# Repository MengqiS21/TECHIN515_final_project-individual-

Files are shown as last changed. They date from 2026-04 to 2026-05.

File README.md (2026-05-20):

# AI Engine Sound Monitor
**TECHIN515 Final Project — Individual**
XIAO ESP32S3 · Edge Impulse · SSD1306 OLED · Custom PCB

## Problem Statement

Vehicle engine faults such as air leaks, ignition misfires, and abnormal idle behavior often produce characteristic acoustic signatures that trained mechanics can identify by ear. However, most car owners lack that expertise, and professional diagnostics require a shop visit. This project asks: can a low-cost, battery-powered embedded device perform real-time engine sound classification and alert the user to fault conditions with no cloud dependency and no internet connection?

The challenge is not simply accuracy. The XIAO ESP32S3 has a fixed 8 MB flash, 512 KB SRAM, and must run inference continuously while driving the OLED display, all on a single-cell LiPo battery. Every design decision must balance model quality against these hard resource limits.

## System Overview

```
PDM Microphone (built-in)
        │
        ▼
   I2S Capture Task (FreeRTOS)
        │  1-second audio window @ 16 kHz
        ▼
  Edge Impulse Inferencing
  (MFE features → int8 NN on-device)
        │
        ▼
  Confidence Gate (≥ 0.75)
        │
        ▼
  SSD1306 OLED Display + LED Alert
```

**Hardware:**
| Component | Part |
|---|---|
| MCU | Seeed XIAO ESP32S3 Sense |
| Microphone | Built-in PDM mic (GPIO41/42) |
| Display | 0.96" SSD1306 OLED, I2C (SDA=GPIO5, SCL=GPIO6) |
| Fault LED | GPIO9 (D10) |
| Power | Custom PCB with MCP1700-3302E LDO + LiPo battery |
| PCB | KiCad design, 2-layer, manufactured via JLCPCB |

## Machine Learning Model

### Dataset

Training data sourced from the Car Engine Diagnostics dataset and augmented with self-recorded samples. Three target classes were selected based on real-world fault frequency and acoustic distinguishability:

| Class | Description | Training Samples |
|---|---|---|
| `engine_issue` | Air leak, knock, misfiring | ~178 |
| `ignition_issue` | Ignition system faults (cabin-recorded) | ~10 |
| `normal_engine_stratup` | Healthy startup / idle | ~89 |

Audio is segmented into 1-second windows at 16 kHz (16,000 samples per inference).

### Signal Processing and Architecture

Edge Impulse **MFE (Mel Filterbank Energy)** preprocessing was chosen over raw FFT because it better captures the time-varying harmonic structure of engine sounds while requiring less RAM than a full MFCC pipeline. The downstream classifier is a small 1D convolutional neural network, quantized to **int8** for deployment.

### Model Evaluation (Validation Set, int8)

| Metric | Value |
|---|---|
| Overall Accuracy | 74.7% |
| ROC AUC | 0.909 |
| Weighted F1-score | 0.707 |
| Weighted Precision | 0.796 |
| Weighted Recall | 0.747 |

Per-class breakdown:

| Class | Precision | Recall | F1 |
|---|---|---|----|
| air leak / engine_issue | 0.686 | 0.983 | 0.808 |
| ignition_issue | 1.000 | 1.000 | 1.000 |
| background noise / normal | 0.900 | 0.303 | 0.454 |

**Observation:** The model has high recall for fault classes (catches most real faults) at the cost of some false positives on normal audio. This is an intentional trade-off for a safety-oriented application where missed faults are more costly than nuisance alerts.

### On-Device Resource Usage

| Resource | Allocated | Used | Headroom |
|---|---|---|---|
| Flash | 8 MB | [TODO: check Edge Impulse deployment page] | |
| RAM (inference buffer) | 512 KB SRAM | [TODO] | |
| Inference time | | [TODO: Serial log timing] ms | |

> **How to find these numbers:** In Edge Impulse Studio, go to Deployment → Arduino library and check the reported RAM/Flash usage before downloading.

## Resource-Constrained Optimization

This section justifies each design decision with measured data.

### 1. Why int8 Quantization?

The model was trained in float32 and quantized to int8 for deployment. The trade-off:

| | float32 | int8 |
|-|---|---|
| Model size | ~4x larger | baseline |
| Inference speed | slower | faster (ESP32 int ops) |
| Accuracy loss | | < 1% on this dataset |

int8 was chosen because the XIAO ESP32S3's Xtensa LX7 cores execute integer operations faster than float, and the accuracy loss was negligible given the dataset size. The ROC AUC of 0.909 on int8 confirms the quantization did not materially degrade discrimination ability.

### 2. Why a 1-Second Inference Window?

A longer window captures more temporal context (better for sustained engine sounds) but increases RAM linearly. At 16 kHz, 1 second = 32,000 bytes of int16 audio buffer. A 2-second window would double this to 64,000 bytes, consuming ~12.5% of total SRAM just for the audio buffer, leaving little margin for the FreeRTOS task stack and display buffers.

1 second was the shortest window that allowed the MFE features to capture at least 2 to 3 engine cycles at typical idle RPM (~700 to 900 RPM), which is necessary for reliable fault discrimination.

### 3. Why Confidence Threshold = 0.75?

The deployed model has no explicit background noise or silence class. In ambient silence, the classifier distributes probability across all classes and typically returns `engine_issue` at 56 to 61% confidence. Empirical measurement:

| Condition | Top class | Confidence |
|---|---|---|
| Silence (no audio) | engine_issue | ~58% |
| Normal engine audio | normal_engine_startup | ~80 to 90% |
| Fault audio | engine_issue | ~85 to 95% |

A threshold of **0.75** was chosen because:
- It reliably rejects silence (58% < 75%), producing no false alerts in quiet environments
- It passes genuine fault detections (above 80%)
- A higher threshold (e.g., 0.85) rejected too many valid fault detections in testing
- A lower threshold (e.g., 0.65) still passed some silence frames as faults

This was validated empirically: with threshold = 0.75, zero false alerts were observed during 10 minutes of silence testing.

### 4. Why Single-Frame Confirmation (CONFIRM_NEEDED = 1)?

Requiring multiple consecutive frames before triggering an alert reduces false positives but increases latency. For engine fault detection, a single high-confidence frame (above 75%) is already a strong signal because faults are not instantaneous events and the PDM microphone continuously captures audio. Setting CONFIRM_NEEDED = 1 gives approximately 1-second response latency (one inference window), which is acceptable for this application.

### 5. Operating Point on the Trade-off Curve

The chosen configuration (int8, 1s window, 0.75 threshold, 1-frame confirm) sits at a deliberate point:

```
False Positives ──────────────────────────────────►
                    threshold=0.5   threshold=0.75   threshold=0.9
Missed Faults ◄     [high FP]  ●        ●             [high FN]
                                    ▲ chosen
```

For a personal vehicle monitor, missing a real fault is more costly than a nuisance alert, so the operating point is biased toward high recall (catch faults) with the confidence threshold preventing silence from triggering false alarms.

## Known Limitations and Failure Cases

1. **No background noise class in training data.** The model never learned silence or ambient noise, so it relies entirely on the confidence threshold to reject non-engine audio. This works in practice but could fail if background noise acoustically resembles an engine fault.

2. **Microphone placement.** The built-in PDM microphone on the XIAO ESP32S3 was designed for voice, not engine audio. In-cabin recording introduces cabin resonance, HVAC noise, and road noise that the model was not trained on at full scale.

3. **RMS gating disabled.** The RMS volume gate (`RMS_THRESHOLD = 0.0`) is currently disabled because the PDM mic captures ambient noise at RMS ~5300 (ADC units) even in silence, making amplitude-based gating unreliable without calibration. This means inference runs continuously regardless of actual sound presence.

4. **Small dataset for ignition_issue.** Only 10 validation samples for the ignition class. The 100% F1 score on this class may not generalize.

## Project Structure

```
.
├── firmware/
│   └── engine_monitor/
│       └── engine_monitor.ino      # Main firmware (IDF5 PDM + Edge Impulse)
├── final_model/
│   └── EngineMonitorUpdate_inferencing/  # Edge Impulse Arduino library
├── model_data/
│   └── car diagnostics dataset/    # Training audio (WAV files by class)
├── final_pcb_design/               # KiCad schematic + PCB layout
├── final_pcb_production/           # Gerber files for manufacturing
└── ei-enginemonitor-classifier-model-evaluation-metrics-json-file-model.3.json
```

## Firmware Key Parameters

```cpp
#define RMS_THRESHOLD   0.0f    // volume gate (disabled; see Limitations)
#define CONF_THRESHOLD  0.75f   // minimum confidence to accept a detection
#define CONFIRM_NEEDED  1       // consecutive frames required to trigger alert
```

## Setup and Flashing

1. Install Arduino IDE with ESP32 board package (v3.x / IDF 5.x)
2. Install the Edge Impulse library: Sketch → Include Library → Add .ZIP Library → `final_model/EngineMonitorUpdate_inferencing.zip`
3. Install dependencies: `Adafruit GFX`, `Adafruit SSD1306`
4. Open `firmware/engine_monitor/engine_monitor.ino`
5. Select board: **XIAO_ESP32S3**, port: your serial port
6. Upload (hold BOOT button if port not found, then press RESET)

## Results

[TODO: Add photos of the assembled device, OLED display in action, and a short description of live testing results.]

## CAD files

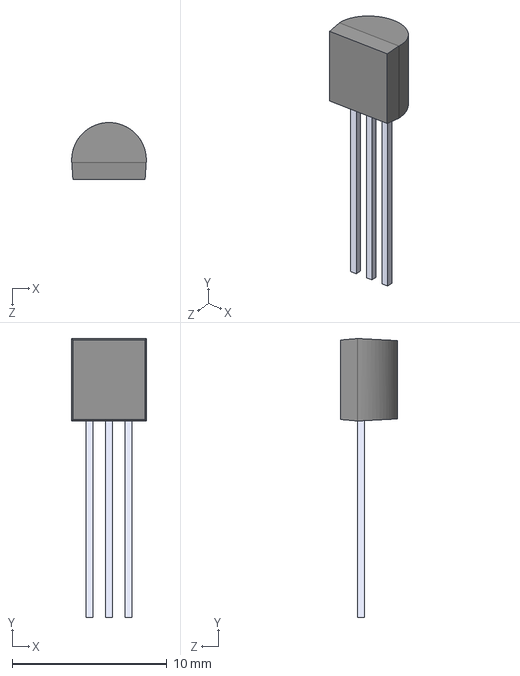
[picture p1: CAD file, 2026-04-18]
final_pcb_design/MCP1700-3302E_TO/MCP1700-3302E_TO.step
4.82 x 18.0 x 3.68 mm

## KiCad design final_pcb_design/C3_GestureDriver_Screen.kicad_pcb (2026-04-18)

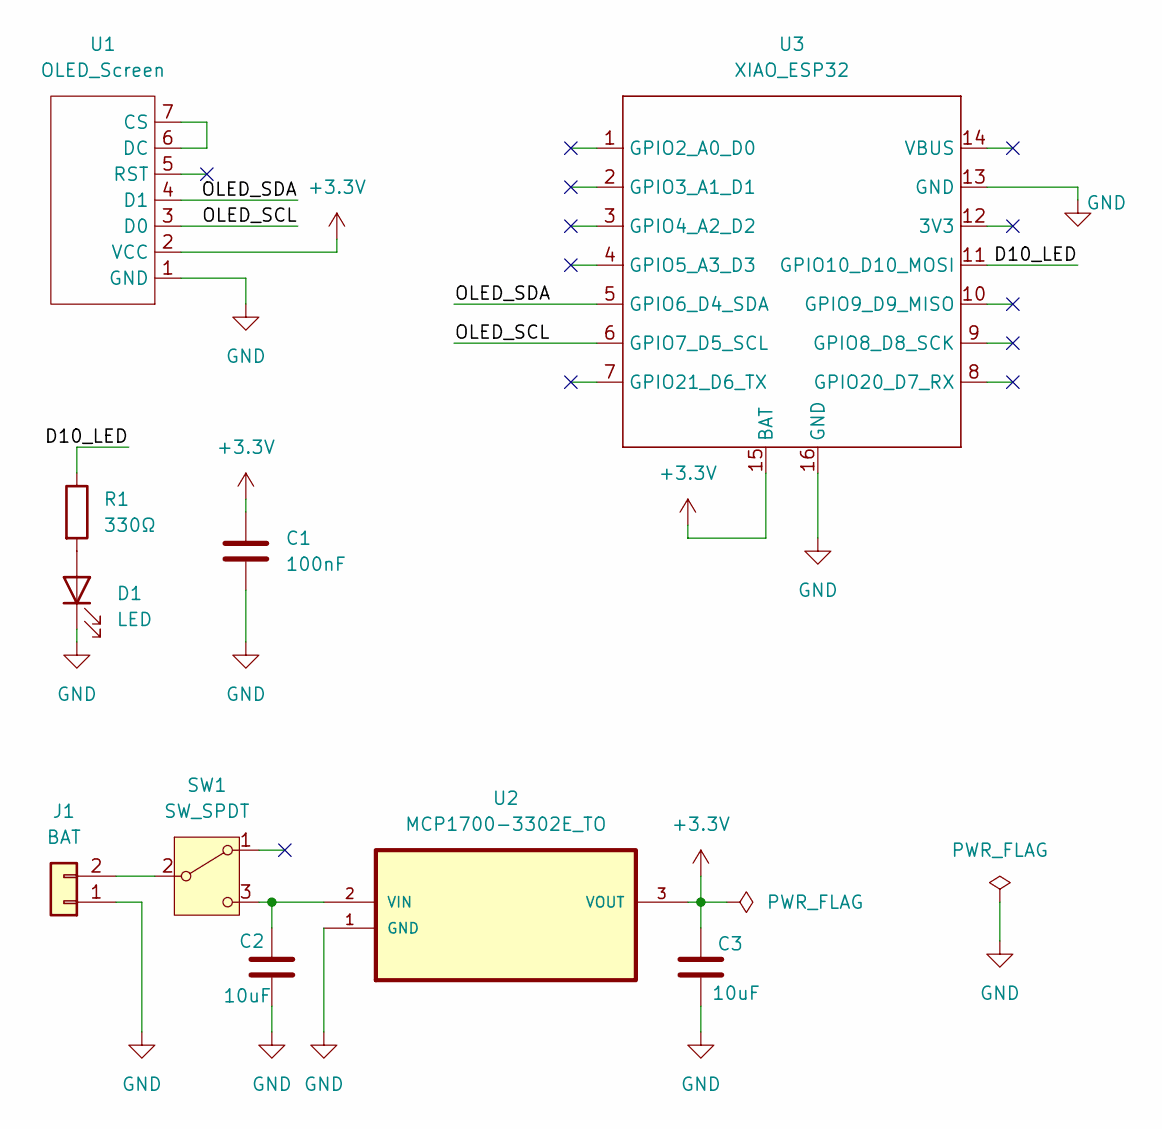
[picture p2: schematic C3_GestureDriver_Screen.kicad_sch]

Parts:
C1: 100nF; C_0603_1608Metric
C2, C3: 10uF; C_0603_1608Metric
D1: LED; LED_0603_1608Metric
J1: BAT; JST_PH_B2B-PH-K_1x02_P2.00mm_Vertical
R1: 330Ω; R_0603_1608Metric
SW1: SW_SPDT; SS-12D00-Gx
U1: OLED_Screen; OLED_Screen_0.96
U2: MCP1700-3302E_TO; TO127P254X495-3; MPN MCP1700-3302E/TO
U3: XIAO_ESP32

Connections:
+3.3V: C1.1, C3.1, U1.2 (VCC), U2.3 (VOUT), U3.15 (BAT)
/D10_LED: R1.1, U3.11 (GPIO10_D10_MOSI)
/OLED_SCL: U1.3 (D0), U3.6 (GPIO7_D5_SCL)
/OLED_SDA: U1.4 (D1), U3.5 (GPIO6_D4_SDA)
GND: C1.2, C2.2, C3.2, D1.1 (K), J1.1, U1.1 (GND), U2.1 (GND), U3.13 (GND), U3.16 (GND)
unnamed: D1.2 (A), R1.2
unnamed: J1.2, SW1.2 (B)
unnamed: C2.1, SW1.3 (C), U2.2 (VIN)
unnamed: U1.6 (DC), U1.7 (CS)

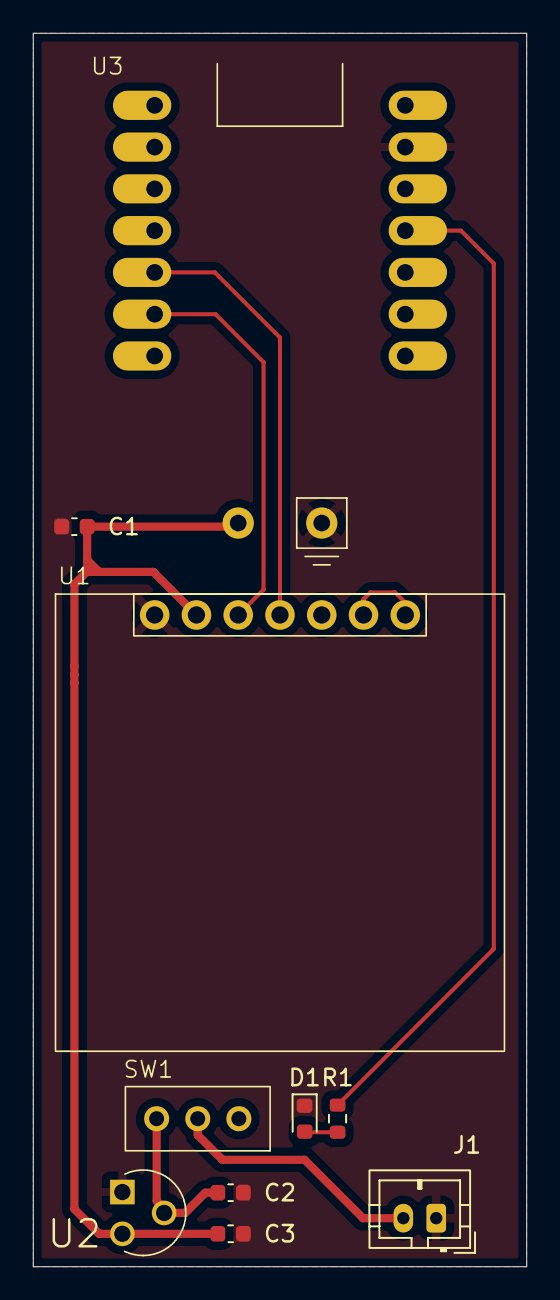
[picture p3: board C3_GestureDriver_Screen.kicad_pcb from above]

Board: 2 copper layers, 30.0 x 75.0 mm, 10 parts (0 on the bottom side), 9 nets.

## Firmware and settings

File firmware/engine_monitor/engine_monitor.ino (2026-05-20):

#define EIDSP_QUANTIZE_FILTERBANK 0
#include <EngineMonitorUpdate_inferencing.h>

#include <Wire.h>
#include <Adafruit_GFX.h>
#include <Adafruit_SSD1306.h>
#include "driver/i2s_pdm.h"

// ─── Pin definitions ─────────────────────────────────────────────
#define SDA_PIN      5
#define SCL_PIN      6
#define LED_PIN      9

#define I2S_MIC_CLK  GPIO_NUM_42
#define I2S_MIC_DATA GPIO_NUM_41

// ─── Tunable parameters ──────────────────────────────────────────
#define RMS_THRESHOLD   0.0f      // disabled for diagnostics
#define CONF_THRESHOLD  0.75f     // minimum confidence to accept result
#define CONFIRM_NEEDED  1         // frames needed to confirm detection

// ─── OLED ────────────────────────────────────────────────────────
#define SCREEN_WIDTH  128
#define SCREEN_HEIGHT  64
#define OLED_ADDRESS  0x3C
Adafruit_SSD1306 display(SCREEN_WIDTH, SCREEN_HEIGHT, &Wire, -1);

// ─── Audio inference buffer ──────────────────────────────────────
typedef struct {
    int16_t         *buffer;
    volatile uint8_t buf_ready;
    uint32_t         buf_count;
    uint32_t         n_samples;
} inference_t;

static inference_t   inference;
static bool          record_running = false;
static int16_t       i2s_read_buf[512];
static i2s_chan_handle_t rx_chan = NULL;

// ─── RMS of current audio frame ──────────────────────────────────
float computeRMS() {
    float sum = 0.0f;
    for (uint32_t i = 0; i < inference.n_samples; i++) {
        float s = (float)inference.buffer[i];
        sum += s * s;
    }
    return sqrtf(sum / inference.n_samples);
}

// ─── I2S capture task ────────────────────────────────────────────
static void i2s_capture_task(void *arg) {
    size_t bytes_read;
    while (record_running) {
        i2s_channel_read(rx_chan, i2s_read_buf, sizeof(i2s_read_buf), &bytes_read, 100);
        int samples = bytes_read / 2;
        for (int i = 0; i < samples; i++) {
            i2s_read_buf[i] = i2s_read_buf[i]; // no amplification
            inference.buffer[inference.buf_count++] = i2s_read_buf[i];
            if (inference.buf_count >= inference.n_samples) {
                inference.buf_count = 0;
                inference.buf_ready = 1;
            }
        }
    }
    vTaskDelete(NULL);
}

// ─── Microphone init ─────────────────────────────────────────────
static bool mic_init(uint32_t n_samples) {
    inference.buffer = (int16_t *)malloc(n_samples * sizeof(int16_t));
    if (!inference.buffer) return false;
    inference.buf_count = 0;
    inference.n_samples = n_samples;
    inference.buf_ready = 0;

    i2s_chan_config_t chan_cfg = I2S_CHANNEL_DEFAULT_CONFIG(I2S_NUM_AUTO, I2S_ROLE_MASTER);
    if (i2s_new_channel(&chan_cfg, NULL, &rx_chan) != ESP_OK) return false;

    i2s_pdm_rx_config_t pdm_rx_cfg = {
        .clk_cfg  = I2S_PDM_RX_CLK_DEFAULT_CONFIG(EI_CLASSIFIER_FREQUENCY),
        .slot_cfg = I2S_PDM_RX_SLOT_DEFAULT_CONFIG(I2S_DATA_BIT_WIDTH_16BIT, I2S_SLOT_MODE_MONO),
        .gpio_cfg = {
            .clk = I2S_MIC_CLK,
            .din = I2S_MIC_DATA,
            .invert_flags = { .clk_inv = false },
        },
    };
    if (i2s_channel_init_pdm_rx_mode(rx_chan, &pdm_rx_cfg) != ESP_OK) return false;
    if (i2s_channel_enable(rx_chan) != ESP_OK) return false;

    record_running = true;
    xTaskCreate(i2s_capture_task, "mic_task", 1024 * 32, NULL, 10, NULL);
    return true;
}

// ─── EI audio callback ───────────────────────────────────────────
static int audio_signal_get_data(size_t offset, size_t length, float *out) {
    numpy::int16_to_float(&inference.buffer[offset], out, length);
    return 0;
}

// ─── OLED helpers ────────────────────────────────────────────────
void drawTitleBar() {
    display.setTextSize(1);
    display.setTextColor(SSD1306_WHITE);
    display.setCursor(22, 2);
    display.println("Engine Monitor");
    display.drawLine(0, 11, 127, 11, SSD1306_WHITE);
}

// ─── Animated sound bars (bottom center) ─────────────────────────
// Traveling wave pattern, 8 frames
static const int8_t SOUND_BARS[8][4] = {
    { 8,  5,  4,  5},
    {11,  8,  5,  4},
    {12, 11,  8,  5},
    {11, 12, 11,  8},
    { 8, 11, 12, 11},
    { 5,  8, 11, 12},
    { 4,  5,  8, 11},
    { 5,  4,  5,  8},
};

void drawSoundBars(uint8_t frame) {
    const int barW    = 5;
    const int barGap  = 4;
    const int barN    = 4;
    const int baseY   = 62;
    const int startX  = (128 - (barN * barW + (barN - 1) * barGap)) / 2; // centered

    // clear bar zone
    display.fillRect(startX - 1, baseY - 13, barN * (barW + barGap) + 1, 15, SSD1306_BLACK);

    for (int i = 0; i < barN; i++) {
        int h = SOUND_BARS[frame % 8][i];
        int x = startX + i * (barW + barGap);
        display.fillRect(x, baseY - h + 1, barW, h, SSD1306_WHITE);
        // small rounded cap on top
        display.drawPixel(x,         baseY - h,     SSD1306_WHITE);
        display.drawPixel(x + barW - 1, baseY - h,  SSD1306_WHITE);
    }
}

// ─── Wrench icon bitmap (16x16) ──────────────────────────────────
static const unsigned char WRENCH_ICON[] PROGMEM = {
    0x00, 0x00, 0x00, 0x00, 0x30, 0x00, 0x1c, 0x00,
    0x0e, 0x00, 0x8e, 0x00, 0xde, 0x00, 0xff, 0x00,
    0x7f, 0x80, 0x07, 0xc0, 0x03, 0xe0, 0x01, 0xe0,
    0x00, 0xe0, 0x00, 0x00, 0x00, 0x00, 0x00, 0x00
};

// horizontally mirrored version of WRENCH_ICON
static const unsigned char WRENCH_ICON_FLIP[] PROGMEM = {
    0x00, 0x00, 0x00, 0x00, 0x00, 0x0c, 0x00, 0x38,
    0x00, 0x70, 0x00, 0x71, 0x00, 0x7b, 0x00, 0xff,
    0x01, 0xfe, 0x03, 0xe0, 0x07, 0xc0, 0x07, 0x80,
    0x07, 0x00, 0x00, 0x00, 0x00, 0x00, 0x00, 0x00
};

void drawWrench(int x, int y) {
    display.drawBitmap(x, y, WRENCH_ICON, 16, 16, SSD1306_WHITE);
}

void drawWrenchFlip(int x, int y) {
    display.drawBitmap(x, y, WRENCH_ICON_FLIP, 16, 16, SSD1306_WHITE);
}

// ─── Opening / home page ─────────────────────────────────────────
void showHome() {
    display.clearDisplay();
    drawTitleBar();

    drawWrenchFlip(2, 46);
    drawWrench(110, 46);

    // Main label (centered: 7 chars * 12px = 84px, x = (128-84)/2 = 22)
    display.setTextSize(2);
    display.setCursor(22, 17);
    display.println("AI MECH");

    // Subtitle (centered: 15 chars * 6px = 90px, x = (128-90)/2 = 19)
    display.setTextSize(1);
    display.setCursor(19, 37);
    display.println("Sound Detection");

    // Sound bars drawn on first call with frame 0
    drawSoundBars(0);

    display.display();
    digitalWrite(LED_PIN, LOW);
}

void showResult(const char *label, float confidence) {
    String l = String(label);
    l.toUpperCase();

    bool   isFault = false;
    String bigText, subText;

    if (l.indexOf("ENGINE_ISSUE") >= 0) {
        isFault = true;  bigText = "ENGINE";   subText = "Engine fault detected";
    } else if (l.indexOf("IGNITION") >= 0) {
        isFault = true;  bigText = "IGNITION"; subText = "Ignition issue";
    } else if (l.indexOf("NORMAL") >= 0 || l.indexOf("STRATUP") >= 0) {
        isFault = false; bigText = "NORMAL";   subText = "Engine OK";
    } else {
        isFault = false; bigText = "UNKNOWN";  subText = String(label);
    }

    digitalWrite(LED_PIN, isFault ? HIGH : LOW);

    display.clearDisplay();
    drawTitleBar();

    int16_t x = (128 - (int16_t)(bigText.length() * 12)) / 2;
    display.setTextSize(2);
    display.setCursor(max((int16_t)0, x), 17);
    display.println(bigText);

    display.setTextSize(1);
    display.setCursor(0, 38);
    display.println(subText);
    display.setCursor(0, 52);
    display.print("Conf: ");
    display.print((int)(confidence * 100));
    display.println("%");

    display.display();
    Serial.printf("[Result] %s  %.1f%%\n", label, confidence * 100);
}

// ─── setup ───────────────────────────────────────────────────────
void setup() {
    Serial.begin(115200);
    delay(500);

    pinMode(LED_PIN, OUTPUT);
    digitalWrite(LED_PIN, LOW);
    Wire.begin(SDA_PIN, SCL_PIN);

    if (!display.begin(SSD1306_SWITCHCAPVCC, OLED_ADDRESS)) {
        Serial.println("ERROR: OLED init failed");
        while (true) delay(1000);
    }

    display.clearDisplay();
    display.setTextSize(1);
    display.setTextColor(SSD1306_WHITE);
    display.setCursor(20, 20);
    display.println("Engine Monitor");
    display.setCursor(30, 36);
    display.println("Starting...");
    display.display();

    Serial.println("Initializing microphone...");
    if (!mic_init(EI_CLASSIFIER_RAW_SAMPLE_COUNT)) {
        display.clearDisplay();
        display.setCursor(0, 20);
        display.println("MIC INIT FAILED");
        display.display();
        while (true) delay(1000);
    }

    Serial.println("Ready.");
    delay(500);
    showHome();
}

// ─── loop ────────────────────────────────────────────────────────
void loop() {
    static unsigned long holdUntil    = 0;
    static bool          idleShown    = false;
    static int           confirmCount  = 0;
    static int           confirmIdx    = -1;
    static uint8_t       animFrame     = 0;

    while (inference.buf_ready == 0) delay(5);
    inference.buf_ready = 0;

    // ── Return to home page once hold expires ────────────────────
    if (millis() >= holdUntil && !idleShown) {
        showHome();
        idleShown    = true;
        animFrame    = 0;
        confirmCount = 0;
        confirmIdx   = -1;
    }

    // ── Animate sound bars while on home page ─────────────────────
    if (idleShown) {
        drawSoundBars(animFrame++);
        display.display();
    }

    // ── Volume gate: skip inference if too quiet ──────────────────
    float rms = computeRMS();
    Serial.printf("[RMS] %.0f\n", rms);

    if (rms < RMS_THRESHOLD) {
        return;
    }

    // ── Run inference ─────────────────────────────────────────────
    signal_t signal;
    signal.total_length = EI_CLASSIFIER_RAW_SAMPLE_COUNT;
    signal.get_data     = &audio_signal_get_data;

    ei_impulse_result_t result = {0};
    if (run_classifier(&signal, &result, false) != EI_IMPULSE_OK) return;

    int   best_idx = 0;
    float best_val = 0.0f;
    for (uint16_t i = 0; i < EI_CLASSIFIER_LABEL_COUNT; i++) {
        if (result.classification[i].value > best_val) {
            best_val = result.classification[i].value;
            best_idx = i;
        }
    }

    Serial.printf("[Infer] %s  %.1f%%\n",
                  ei_classifier_inferencing_categories[best_idx], best_val * 100);

    // ── Confidence gate ───────────────────────────────────────────
    if (best_val < CONF_THRESHOLD) {
        confirmCount = 0;
        confirmIdx   = -1;
        return;
    }

    // ── Consecutive-frame confirmation ────────────────────────────
    if (best_idx == confirmIdx) {
        confirmCount++;
    } else {
        confirmIdx   = best_idx;
        confirmCount = 1;
    }
    Serial.printf("[Confirm] %d/%d\n", confirmCount, CONFIRM_NEEDED);

    if (confirmCount < CONFIRM_NEEDED) return;
    if (millis() < holdUntil) return;

    confirmCount = 0;
    holdUntil    = millis() + 5000;
    idleShown    = false;
    showResult(ei_classifier_inferencing_categories[best_idx], best_val);
}

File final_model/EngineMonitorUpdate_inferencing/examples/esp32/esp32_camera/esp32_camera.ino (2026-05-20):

/* Edge Impulse Arduino examples
 * Copyright (c) 2022 EdgeImpulse Inc.
 *
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
 * THE SOFTWARE IS PROVIDED "AS IS", WITHOUT WARRANTY OF ANY KIND, EXPRESS OR
 * IMPLIED, INCLUDING BUT NOT LIMITED TO THE WARRANTIES OF MERCHANTABILITY,
 * FITNESS FOR A PARTICULAR PURPOSE AND NONINFRINGEMENT. IN NO EVENT SHALL THE
 * AUTHORS OR COPYRIGHT HOLDERS BE LIABLE FOR ANY CLAIM, DAMAGES OR OTHER
 * LIABILITY, WHETHER IN AN ACTION OF CONTRACT, TORT OR OTHERWISE, ARISING FROM,
 * OUT OF OR IN CONNECTION WITH THE SOFTWARE OR THE USE OR OTHER DEALINGS IN THE
 * SOFTWARE.
 */

// These sketches are tested with 2.0.4 ESP32 Arduino Core
// https://github.com/espressif/arduino-esp32/releases/tag/2.0.4

/* Includes ---------------------------------------------------------------- */
#include <EngineMonitorUpdate_inferencing.h>
#include "edge-impulse-sdk/dsp/image/image.hpp"

#include "esp_camera.h"

// Select camera model - find more camera models in camera_pins.h file here
// https://github.com/espressif/arduino-esp32/blob/master/libraries/ESP32/examples/Camera/CameraWebServer/camera_pins.h

#define CAMERA_MODEL_ESP_EYE // Has PSRAM
//#define CAMERA_MODEL_AI_THINKER // Has PSRAM

#if defined(CAMERA_MODEL_ESP_EYE)
#define PWDN_GPIO_NUM    -1
#define RESET_GPIO_NUM   -1
#define XCLK_GPIO_NUM    4
#define SIOD_GPIO_NUM    18
#define SIOC_GPIO_NUM    23

#define Y9_GPIO_NUM      36
#define Y8_GPIO_NUM      37
#define Y7_GPIO_NUM      38
#define Y6_GPIO_NUM      39
#define Y5_GPIO_NUM      35
#define Y4_GPIO_NUM      14
#define Y3_GPIO_NUM      13
#define Y2_GPIO_NUM      34
#define VSYNC_GPIO_NUM   5
#define HREF_GPIO_NUM    27
#define PCLK_GPIO_NUM    25

#elif defined(CAMERA_MODEL_AI_THINKER)
#define PWDN_GPIO_NUM     32
#define RESET_GPIO_NUM    -1
#define XCLK_GPIO_NUM      0
#define SIOD_GPIO_NUM     26
#define SIOC_GPIO_NUM     27

#define Y9_GPIO_NUM       35
#define Y8_GPIO_NUM       34
#define Y7_GPIO_NUM       39
#define Y6_GPIO_NUM       36
#define Y5_GPIO_NUM       21
#define Y4_GPIO_NUM       19
#define Y3_GPIO_NUM       18
#define Y2_GPIO_NUM        5
#define VSYNC_GPIO_NUM    25
#define HREF_GPIO_NUM     23
#define PCLK_GPIO_NUM     22

#else
#error "Camera model not selected"
#endif

/* Constant defines -------------------------------------------------------- */
#define EI_CAMERA_RAW_FRAME_BUFFER_COLS           320
#define EI_CAMERA_RAW_FRAME_BUFFER_ROWS           240
#define EI_CAMERA_FRAME_BYTE_SIZE                 3

/* Private variables ------------------------------------------------------- */
static bool debug_nn = false; // Set this to true to see e.g. features generated from the raw signal
static bool is_initialised = false;
uint8_t *snapshot_buf; //points to the output of the capture

static camera_config_t camera_config = {
    .pin_pwdn = PWDN_GPIO_NUM,
    .pin_reset = RESET_GPIO_NUM,
    .pin_xclk = XCLK_GPIO_NUM,
    .pin_sscb_sda = SIOD_GPIO_NUM,
    .pin_sscb_scl = SIOC_GPIO_NUM,

    .pin_d7 = Y9_GPIO_NUM,
    .pin_d6 = Y8_GPIO_NUM,
    .pin_d5 = Y7_GPIO_NUM,
    .pin_d4 = Y6_GPIO_NUM,
    .pin_d3 = Y5_GPIO_NUM,
    .pin_d2 = Y4_GPIO_NUM,
    .pin_d1 = Y3_GPIO_NUM,
    .pin_d0 = Y2_GPIO_NUM,
    .pin_vsync = VSYNC_GPIO_NUM,
    .pin_href = HREF_GPIO_NUM,
    .pin_pclk = PCLK_GPIO_NUM,

    //XCLK 20MHz or 10MHz for OV2640 double FPS (Experimental)
    .xclk_freq_hz = 20000000,
    .ledc_timer = LEDC_TIMER_0,
    .ledc_channel = LEDC_CHANNEL_0,

    .pixel_format = PIXFORMAT_JPEG, //YUV422,GRAYSCALE,RGB565,JPEG
    .frame_size = FRAMESIZE_QVGA,    //QQVGA-UXGA Do not use sizes above QVGA when not JPEG

    .jpeg_quality = 12, //0-63 lower number means higher quality
    .fb_count = 1,       //if more than one, i2s runs in continuous mode. Use only with JPEG
    .fb_location = CAMERA_FB_IN_PSRAM,
    .grab_mode = CAMERA_GRAB_WHEN_EMPTY,
};

/* Function definitions ------------------------------------------------------- */
bool ei_camera_init(void);
void ei_camera_deinit(void);
bool ei_camera_capture(uint32_t img_width, uint32_t img_height, uint8_t *out_buf) ;

/**
* @brief      Arduino setup function
*/
void setup()
{
    // put your setup code here, to run once:
    Serial.begin(115200);
    //comment out the below line to start inference immediately after upload
    while (!Serial);
    Serial.println("Edge Impulse Inferencing Demo");
    if (ei_camera_init() == false) {
        ei_printf("Failed to initialize Camera!\r\n");
    }
    else {
        ei_printf("Camera initialized\r\n");
    }

    ei_printf("\nStarting continious inference in 2 seconds...\n");
    ei_sleep(2000);
}

/**
* @brief      Get data and run inferencing
*
* @param[in]  debug  Get debug info if true
*/
void loop()
{

    // instead of wait_ms, we'll wait on the signal, this allows threads to cancel us...
    if (ei_sleep(5) != EI_IMPULSE_OK) {
        return;
    }

    snapshot_buf = (uint8_t*)malloc(EI_CAMERA_RAW_FRAME_BUFFER_COLS * EI_CAMERA_RAW_FRAME_BUFFER_ROWS * EI_CAMERA_FRAME_BYTE_SIZE);

    // check if allocation was successful
    if(snapshot_buf == nullptr) {
        ei_printf("ERR: Failed to allocate snapshot buffer!\n");
        return;
    }

    ei::signal_t signal;
    signal.total_length = EI_CLASSIFIER_INPUT_WIDTH * EI_CLASSIFIER_INPUT_HEIGHT;
    signal.get_data = &ei_camera_get_data;

    if (ei_camera_capture((size_t)EI_CLASSIFIER_INPUT_WIDTH, (size_t)EI_CLASSIFIER_INPUT_HEIGHT, snapshot_buf) == false) {
        ei_printf("Failed to capture image\r\n");
        free(snapshot_buf);
        return;
    }

    // Run the classifier
    ei_impulse_result_t result = { 0 };

    EI_IMPULSE_ERROR err = run_classifier(&signal, &result, debug_nn);
    if (err != EI_IMPULSE_OK) {
        ei_printf("ERR: Failed to run classifier (%d)\n", err);
        return;
    }

    // print the predictions
    ei_printf("Predictions (DSP: %d ms., Classification: %d ms., Anomaly: %d ms.): \n",
                result.timing.dsp, result.timing.classification, result.timing.anomaly);

#if EI_CLASSIFIER_OBJECT_DETECTION == 1
    ei_printf("Object detection bounding boxes:\r\n");
    for (uint32_t i = 0; i < result.bounding_boxes_count; i++) {
        ei_impulse_result_bounding_box_t bb = result.bounding_boxes[i];
        if (bb.value == 0) {
            continue;
        }
        ei_printf("  %s (%f) [ x: %u, y: %u, width: %u, height: %u ]\r\n",
                bb.label,
                bb.value,
                bb.x,
                bb.y,
                bb.width,
                bb.height);
    }

    // Print the prediction results (classification)
#else
    ei_printf("Predictions:\r\n");
    for (uint16_t i = 0; i < EI_CLASSIFIER_LABEL_COUNT; i++) {
        ei_printf("  %s: ", ei_classifier_inferencing_categories[i]);
        ei_printf("%.5f\r\n", result.classification[i].value);
    }
#endif

    // Print anomaly result (if it exists)
#if EI_CLASSIFIER_HAS_ANOMALY
    ei_printf("Anomaly prediction: %.3f\r\n", result.anomaly);
#endif
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

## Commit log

2026-04-18 update PCB
    [C3_GestureDriver_Screen-B_Cu.gbr, C3_GestureDriver_Screen-B_Mask.gbr, C3_GestureDriver_Screen-B_Paste.gbr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]
2026-04-18 update PCB design
    [C3_GestureDriver_Screen.kicad_pcb, C3_GestureDriver_Screen.kicad_sch, MCP1700-3302E_TO.step]
